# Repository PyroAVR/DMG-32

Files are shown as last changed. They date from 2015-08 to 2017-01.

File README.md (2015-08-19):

Emulator Project
================
I don't have a witty name for this...  This repository contains all the things necessary for making a working Retroarch emulator that fits inside a DMG GameBoy, -or- later, a custom casing with added awesomeness.
Below are the projects which have been used to build this one...

###What changed?
Here's a list of the changes made to the original Adafruit code.
 -Added a new I/O type.  Support for the Pixel interface board.
 -10-retrogame.rules added.  Just copy it into the `/etc/udev/rules.d/` folder!
 -Added retrogame.sh, it's a really handy sysV start script for retrogame!
 -TODO: recompile new retrogame with Pixel interface board support.
Adafruit-Retrogame
==================

Raspberry Pi GPIO-to-USB utility for classic game emulators.

How-to: http://learn.adafruit.com/retro-gaming-with-raspberry-pi

Pre-built version supports the default pin/key mapping shown in the tutorial. For other layouts, edit retrogame.c.

### RetroPie 2.0+ Compatibility

Note that by default retrogame won't work with SDL2 applications that depend on evdev for input events.  Specifically this means applications like the latest version of RetroPie and EmulationStation won't be able to see key events generated by retrogame.  However you can fix this issue by adding a small custom udev rule to make retrogame keyboard events visible to SDL2.

Connect to your Raspberry Pi in a terminal/SSH session and execute the following command to create and edit the file /etc/udev/rules.d/10-retrogame.rules:

```bash
sudo nano /etc/udev/rules.d/10-retrogame.rules
```

Once the nano text editor loads, copy this single line into the file:

```bash
SUBSYSTEM=="input", ATTRS{name}=="retrogame", ENV{ID_INPUT_KEYBOARD}="1"
```

Save the file by pressing Ctrl-O and enter, then press Ctrl-x to exit.  Restart your Raspberry Pi and run retrogame again, now button presses should register in SDL2 applications like the EmulationStation frontend to RetroPie

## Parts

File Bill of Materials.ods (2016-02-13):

Part Name | Count | Description
Resistor, 10KOhm | 14 | 10KOhm 1/4 or 1/8 Watt through-hole
Tactile Swtich | 12 | 6mm square 7.5mm tall 4 pin SPST
LED | 1 | Any color, 3.3 V 3mm
Pin header | 1 | 2x20 Female Pin header, fits on Rpi GPIO header
Atmel ATTiny85 | 1 | ATTiny85 20MHz 8PDIP
Raspberry Pi | 1 | Pi A+ or Zero will fit the enclosure!

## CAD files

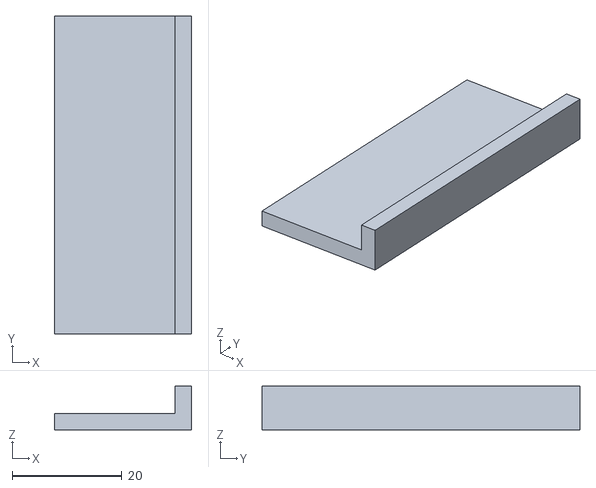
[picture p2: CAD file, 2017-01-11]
case/cardtridge_cover.stl
25.0 x 58.0 x 8.00

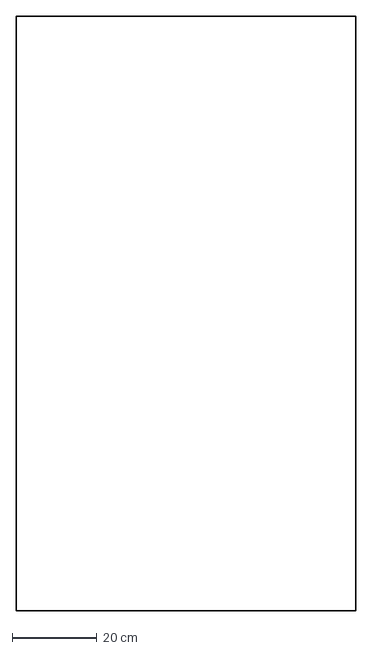
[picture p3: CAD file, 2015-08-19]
Frontboard/BoardOutline.dxf
80.0 x 140.0 cm

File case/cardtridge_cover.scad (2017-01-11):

difference()    {
 cube([25,58,8]);
 translate([0,0,3]) {
  cube([22,58,5]);
 }
}

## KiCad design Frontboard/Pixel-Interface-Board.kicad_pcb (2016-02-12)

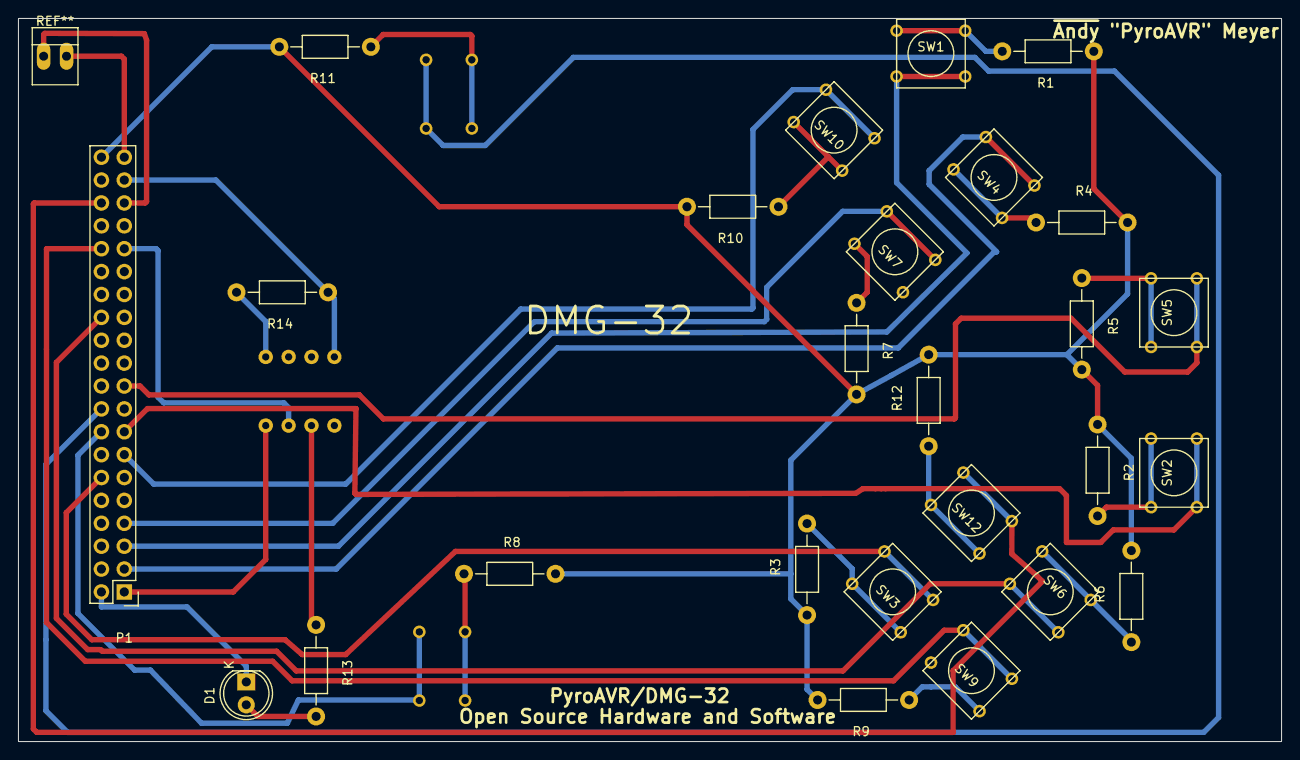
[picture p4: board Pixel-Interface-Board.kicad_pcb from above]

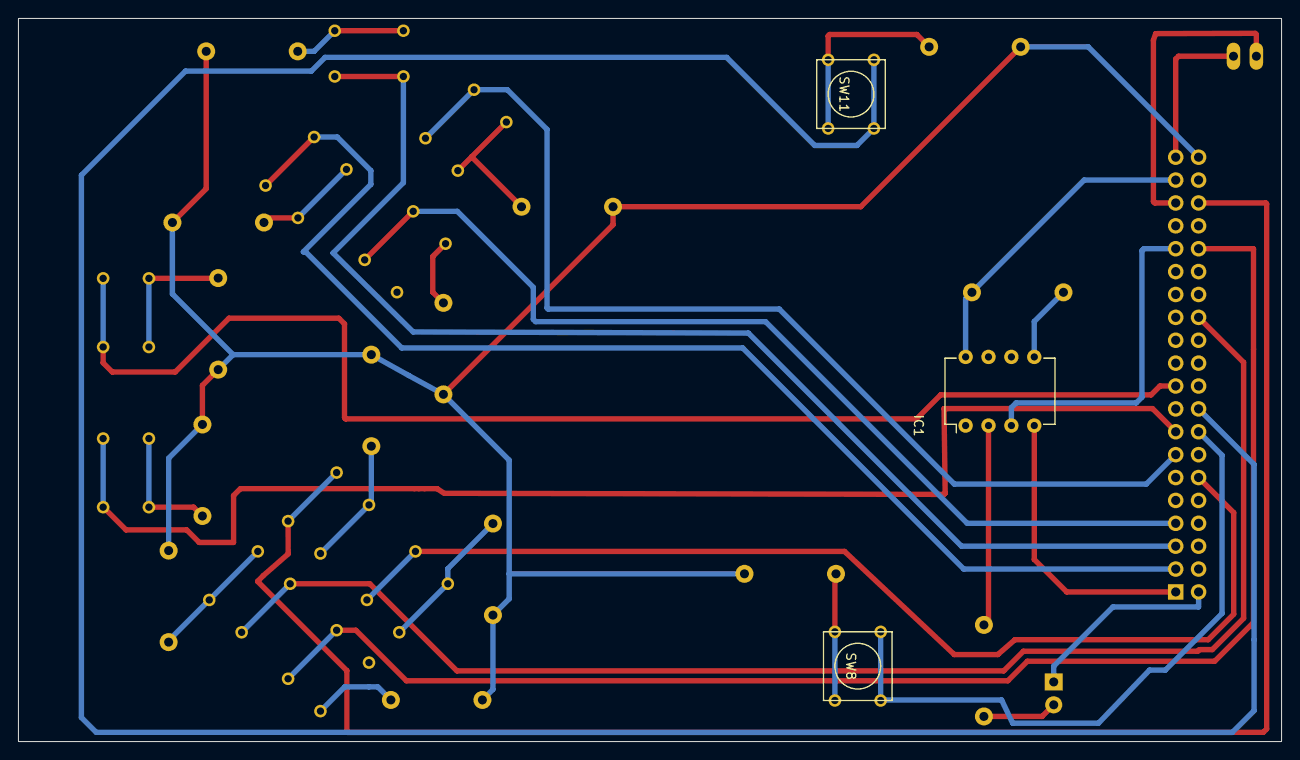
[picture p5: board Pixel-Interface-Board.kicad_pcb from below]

Board: 2 copper layers, 140.2 x 80.3 mm, 29 parts (3 on the bottom side), 31 nets.

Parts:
D1: LED; LED-5MM
IC1: ATTINY85-P; DIP-8_W7.62mm
P1: CONN_02X20; Pin_Header_Straight_2x20
R1, R2, R3, R4, R5, R6, R7, R8, R9, R10, R11, R12, R14: 10K; Resistor_Horizontal_RM10mm
R13: 1K; Resistor_Horizontal_RM10mm
SW1, SW2, SW3, SW4, SW5, SW6, SW7, SW8, SW9, SW10, SW11, SW12: SW_PUSH; SW_PUSH_SMALL

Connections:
/A: P1.5, SW1.2
/B: P1.3, SW4.2
/DOWN: P1.26, SW6.2
/L: P1.16, SW8.2
/LEFT: P1.32, SW9.2
/R: P1.18, SW11.2
/RIGHT: P1.36, SW12.2
/SELECT: P1.15, SW2.2
/START: P1.19, SW5.2
/UART_RX: IC1.3, P1.31
/UP: P1.12, SW3.2
/X: P1.7, SW7.2
/Y: P1.13, SW10.2
GND: D1.1, IC1.4, P1.1, P1.2, P1.9, P1.21, P1.30, P1.34, P1.35
unnamed: D1.2, R13.2
unnamed: IC1.2, R13.1
unnamed: IC1.5, R14.2
unnamed: R1.2, SW1.1
unnamed: R2.2, SW2.1
unnamed: R3.2, SW3.1
unnamed: R4.1, SW4.1
unnamed: R5.1, SW5.1
unnamed: R6.1, SW6.1
unnamed: R7.1, SW7.1
unnamed: R8.1, SW8.1
unnamed: R9.1, SW9.1
unnamed: R10.1, SW10.1
unnamed: R11.1, SW11.1
unnamed: R12.1, SW12.1
VCC: IC1.8, P1.37, P1.39, R14.1
VDD: P1.24, P1.40, R1.1, R2.1, R3.1, R4.2, R5.2, R6.2, R7.2, R8.2, R9.2, R10.2, R11.2, R12.2

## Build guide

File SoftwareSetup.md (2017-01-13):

SOFTWARE SETUP
==========
I/O Pins for Pixel Interface board:
(Make sure these are correct!)
Note that BCM# and GPIO# are synonymous

GPIO NAME         PIN #               FUNCTION          MAP
GPIO3                05               A BUTTON          KEY_A
GPIO2                03               B BUTTON          KEY_B
GPIO4                07               X BUTTON          KEY_X
GPIO27               13               Y BUTTON          KEY_Y
GPIO23               16               L BUTTON          KEY_L
GPIO24               18               R BUTTON          KEY_R
GPIO22               15               SELECT            KEY_N
GPIO10               19               START             KEY_M
GPIO17               11               UP                KEY_UP
GPIO5                26               DOWN              KEY_DOWN
GPIO12               32               LEFT              KEY_LEFT
GPIO16               36               RIGHT             KEY_RIGHT

```C
ioPixel[] = {
//This pin/key table is set up for the tentative Pixel Interface Board,
// which fits quite nicely inside an original DMG Gameboy.
//These mappings are taken directly from the schematic.  For convenience,
//the data has been organized into a neat table, Connectivity Table.ods in this
//repository.
// Input   Output (from /usr/include/linux/input.h)
{   3,     KEY_A  },    // A
{   2,     KEY_B  },    // B
{   4,     KEY_X  },    // X
{  27,     KEY_Y  },    // Y
{  17,     KEY_UP  },   // Up
{   5,     KEY_DOWN  }, // Down
{  12,     KEY_LEFT  }, // Left
{  16,     KEY_RIGHT }, // Right
{  23,     KEY_L  },    // L
{  24,     KEY_R }      // R
{  22,     KEY_N },     // Select
{  10,     KEY_M },     // Start
{  -1,     -1           } }; // END OF LIST, DO NOT CHANGE
```

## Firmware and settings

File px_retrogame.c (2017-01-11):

/*
Pixel RetroGame - An adaptation of Adafruit's Retrogame
http://github.com/Adafruit/Adafruit-retrogame
http://github.com/PyroAVR/DMG-32


Remaps buttons on Raspberry Pi GPIO header
to virtual USB keyboard presses.  Great for classic game emulators!
Retrogame is interrupt-driven and efficient (usually under 0.3% CPU use)
and debounces inputs for glitch-free gaming.

Connect one side of button(s) to GND pin (there are several on the GPIO
header, but see later notes) and the other side to GPIO pin of interest.
Internal pullups are used; no resistors required.  Avoid pins 8 and 10;
these are configured as a serial port by default on most systems (this
can be disabled but takes some doing).  Pin configuration is currently
set in global table; no config file yet.  See later comments.
***
Do not disable the serial port, it is needed for the
power management functionality of the Pixel Interface Board.
Also, a config file is included in the Pixel repository.
***

Must be run as root, i.e. 'sudo ./retrogame &' or configure init scripts
to launch automatically at system startup.
***
The default Pixel image will do this for you.
***

Requires uinput kernel module.  This is typically present on popular
Raspberry Pi Linux distributions but not enabled on some older varieties.
To enable, either type:

    sudo modprobe uinput
  ***
  This is taken care of for you in the Pixel image.
  ***

Or, to make this persistent between reboots, add a line to /etc/modules:

    uinput

Prior versions of this code, when being compiled for use with the Cupcade
or PiGRRL projects, required CUPCADE to be #defined.  This is no longer
the case; instead a test is performed to see if a PiTFT is connected, and
one of two I/O tables is automatically selected.
***
The Pixel code selects its own I/O table by default, and it is
specified in the config file.
***
Written by Phil Burgess for Adafruit Industries, distributed under BSD
License.  Adafruit invests time and resources providing this open source
code, please support Adafruit and open-source hardware by purchasing
products from Adafruit!
***
All the prototypes for the Pixel board, and any necessary components,
were purchased from Adafruit! Thanks for being an inspiration!
***

Copyright (c) 2013 Adafruit Industries, Pixel Productions.
All rights reserved.

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
- Redistributions of source code must retain the above copyright notice,
  this list of conditions and the following disclaimer.
- Redistributions in binary form must reproduce the above copyright notice,
  this list of conditions and the following disclaimer in the documentation
  and/or other materials provided with the distribution.

THIS SOFTWARE IS PROVIDED BY THE COPYRIGHT HOLDERS AND CONTRIBUTORS "AS IS"
AND ANY EXPRESS OR IMPLIED WARRANTIES, INCLUDING, BUT NOT LIMITED TO, THE
IMPLIED WARRANTIES OF MERCHANTABILITY AND FITNESS FOR A PARTICULAR PURPOSE
ARE DISCLAIMED. IN NO EVENT SHALL THE COPYRIGHT HOLDER OR CONTRIBUTORS BE
LIABLE FOR ANY DIRECT, INDIRECT, INCIDENTAL, SPECIAL, EXEMPLARY, OR
CONSEQUENTIAL DAMAGES (INCLUDING, BUT NOT LIMITED TO, PROCUREMENT OF
SUBSTITUTE GOODS OR SERVICES; LOSS OF USE, DATA, OR PROFITS; OR BUSINESS
INTERRUPTION) HOWEVER CAUSED AND ON ANY THEORY OF LIABILITY, WHETHER IN
CONTRACT, STRICT LIABILITY, OR TORT (INCLUDING NEGLIGENCE OR OTHERWISE)
ARISING IN ANY WAY OUT OF THE USE OF THIS SOFTWARE, EVEN IF ADVISED OF THE
POSSIBILITY OF SUCH DAMAGE.
*/
#include "px_retrogame.h"


// A few globals ---------------------------------------------------------

char
  *progName,                         // Program name (for error reporting)
   sysfs_root[] = "/sys/class/gpio", // Location of Sysfs GPIO files
   running      = 1;                 // Signal handler will set to 0 (exit)
volatile unsigned int
  *gpio;                             // GPIO register table
const int
   debounceTime = 20;                // 20 ms for button debouncing


// Some utility functions ------------------------------------------------

// Set one GPIO pin attribute through the Sysfs interface.
int pinConfig(int pin, char *attr, char *value) {
	char filename[50];
	int  fd, w, len = strlen(value);
	sprintf(filename, "%s/gpio%d/%s", sysfs_root, pin, attr);
	if((fd = open(filename, O_WRONLY)) < 0) return -1;
	w = write(fd, value, len);
	close(fd);
	return (w != len); // 0 = success
}

// Un-export any Sysfs pins used; don't leave filesystem cruft.  Also
// restores any GND pins to inputs.  Write errors are ignored as pins
// may be in a partially-initialized state.
void cleanup() {
	char buf[50];
	int  fd, i;
	sprintf(buf, "%s/unexport", sysfs_root);
	if((fd = open(buf, O_WRONLY)) >= 0) {
		for(i=0; io[i].pin >= 0; i++) {
			// Restore GND items to inputs
			if(io[i].key == GND)
				pinConfig(io[i].pin, "direction", "in");
			// And un-export all items regardless
			sprintf(buf, "%d", io[i].pin);
			write(fd, buf, strlen(buf));
		}
		close(fd);
	}
}

// Quick-n-dirty error reporter; print message, clean up and exit.
void err(char *msg) {
	printf("%s: %s.  Try 'sudo %s'.\n", progName, msg, progName);
	cleanup();
	exit(1);
}

// Interrupt handler -- set global flag to abort main loop.
void signalHandler(int n) {
	running = 0;
}

// Detect Pi board type.  Doesn't return super-granular details,
// just the most basic distinction needed for GPIO compatibility:
// 0: Pi 1 Model B revision 1
// 1: Pi 1 Model B revision 2, Model A, Model B+, Model A+
// 2: Pi 2 Model B

static int boardType(void) {
	FILE *fp;
	char  buf[1024], *ptr;
	int   n, board = 1; // Assume Pi1 Rev2 by default

	// Relies on info in /proc/cmdline.  If this becomes unreliable
	// in the future, alt code below uses /proc/cpuinfo if any better.
#if 1
	if((fp = fopen("/proc/cmdline", "r"))) {
		while(fgets(buf, sizeof(buf), fp)) {
			if((ptr = strstr(buf, "mem_size=")) &&
			   (sscanf(&ptr[9], "%x", &n) == 1) &&
			   (n == 0x3F000000)) {
				board = 2; // Appears to be a Pi 2
				break;
			} else if((ptr = strstr(buf, "boardrev=")) &&
			          (sscanf(&ptr[9], "%x", &n) == 1) &&
			          ((n == 0x02) || (n == 0x03))) {
				board = 0; // Appears to be an early Pi
				break;
			}
		}
		fclose(fp);
	}
#else
	char s[8];
	if((fp = fopen("/proc/cpuinfo", "r"))) {
		while(fgets(buf, sizeof(buf), fp)) {
			if((ptr = strstr(buf, "Hardware")) &&
			   (sscanf(&ptr[8], " : %7s", s) == 1) &&
			   (!strcmp(s, "BCM2709"))) {
				board = 2; // Appears to be a Pi 2
				break;
			} else if((ptr = strstr(buf, "Revision")) &&
			          (sscanf(&ptr[8], " : %x", &n) == 1) &&
			          ((n == 0x02) || (n == 0x03))) {
				board = 0; // Appears to be an early Pi
				break;
			}
		}
		fclose(fp);
	}
#endif

	return board;
}

// Main stuff ------------------------------------------------------------

#define PI1_BCM2708_PERI_BASE 0x20000000
#define PI1_GPIO_BASE         (PI1_BCM2708_PERI_BASE + 0x200000)
#define PI2_BCM2708_PERI_BASE 0x3F000000
#define PI2_GPIO_BASE         (PI2_BCM2708_PERI_BASE + 0x200000)
#define BLOCK_SIZE            (4*1024)
#define GPPUD                 (0x94 / 4)
#define GPPUDCLK0             (0x98 / 4)

int main(int argc, char *argv[]) {

	// A few arrays here are declared with 32 elements, even though
	// values aren't needed for io[] members where the 'key' value is
	// GND.  This simplifies the code a bit -- no need for mallocs and
	// tests to create these arrays -- but may waste a handful of
	// bytes for any declared GNDs.
	char                   buf[50],      // For sundry filenames
	                       c,            // Pin input value ('0'/'1')
	                       board;        // 0=Pi1Rev1, 1=Pi1Rev2, 2=Pi2
	int                    fd,           // For mmap, sysfs, uinput
	                       i, j,         // Asst. counter
	                       bitmask,      // Pullup enable bitmask
	                       timeout = -1, // poll() timeout
	                       intstate[32], // Last-read state
	                       extstate[32], // Debounced state
	                       lastKey = -1; // Last key down (for repeat)
	unsigned long          bitMask, bit; // For Vulcan pinch detect
	volatile unsigned char shortWait;    // Delay counter
	struct input_event     keyEv, synEv; // uinput events
	struct pollfd          p[32];        // GPIO file descriptors

	progName = argv[0];             // For error reporting
	signal(SIGINT , signalHandler); // Trap basic signals (exit cleanly)
	signal(SIGKILL, signalHandler);

	// Modified for Pixel devices, so io is set to use ioPixel.
	//As the DMG-32 board doesn't have an EEPROM, no detection is possible.
  //It does have an ATTiny85 though, so it may later be able to emulate this?
  //The only obstacle is that the ATTiny85 is on the Pi's UART pins, and the SPI
  //pins are occupied as GPIO.
  io = ioPixel;

//The interface board does not support older Pis, which likely do not have
//enough GPIO

//The DMG-32 board has pullup resistors on it, whoops!  This probably isn't needed.

	// ----------------------------------------------------------------
	// Although Sysfs provides solid GPIO interrupt handling, there's
	// no interface to the internal pull-up resistors (this is by
	// design, being a hardware-dependent feature).  It's necessary to
	// grapple with the GPIO configuration registers directly to enable
	// the pull-ups.  Based on GPIO example code by Dom and Gert van
	// Loo on elinux.org

	if((fd = open("/dev/mem", O_RDWR | O_SYNC)) < 0)
		err("Can't open /dev/mem");
	gpio = mmap(            // Memory-mapped I/O
	  NULL,                 // Any adddress will do
	  BLOCK_SIZE,           // Mapped block length
	  PROT_READ|PROT_WRITE, // Enable read+write
	  MAP_SHARED,           // Shared with other processes
	  fd,                   // File to map
	  (board == 2) ?
	   PI2_GPIO_BASE :      // -> GPIO registers
	   PI1_GPIO_BASE);

	close(fd);              // Not needed after mmap()
	if(gpio == MAP_FAILED) err("Can't mmap()");
	// Make combined bitmap of pullup-enabled pins:
	for(bitmask=i=0; io[i].pin >= 0; i++)
		if(io[i].key != GND) bitmask |= (1 << io[i].pin);
	gpio[GPPUD]     = 2;                    // Enable pullup
	for(shortWait=150;--shortWait;);        // Min 150 cycle wait
	gpio[GPPUDCLK0] = bitmask;              // Set pullup mask
	for(shortWait=150;--shortWait;);        // Wait again
	gpio[GPPUD]     = 0;                    // Reset pullup registers
	gpio[GPPUDCLK0] = 0;
	(void)munmap((void *)gpio, BLOCK_SIZE); // Done with GPIO mmap()


//From here on out, we're just enabling pins.
	// ----------------------------------------------------------------
	// All other GPIO config is handled through the sysfs interface.

	sprintf(buf, "%s/export", sysfs_root);
	if((fd = open(buf, O_WRONLY)) < 0) // Open Sysfs export file
		err("Can't open GPIO export file");
	for(i=j=0; io[i].pin >= 0; i++) { // For each pin of interest...
		sprintf(buf, "%d", io[i].pin);
		write(fd, buf, strlen(buf));             // Export pin
		pinConfig(io[i].pin, "active_low", "0"); // Don't invert
		if(io[i].key == GND) {
			// Set pin to output, value 0 (ground)
			if(pinConfig(io[i].pin, "direction", "out") ||
			   pinConfig(io[i].pin, "value"    , "0"))
				err("Pin config failed (GND)");
		} else {
			// Set pin to input, detect rise+fall events
			if(pinConfig(io[i].pin, "direction", "in") ||
			   pinConfig(io[i].pin, "edge"     , "both"))
				err("Pin config failed");
			// Get initial pin value
			sprintf(buf, "%s/gpio%d/value",
			  sysfs_root, io[i].pin);
			// The p[] file descriptor array isn't necessarily
			// aligned with the io[] array.  GND keys in the
			// latter are skipped, but p[] requires contiguous
			// entries for poll().  So the pins to monitor are
			// at the head of p[], and there may be unused
			// elements at the end for each GND.  Same applies
			// to the intstate[] and extstate[] arrays.
			if((p[j].fd = open(buf, O_RDONLY)) < 0)
				err("Can't access pin value");
			intstate[j] = 0;
			if((read(p[j].fd, &c, 1) == 1) && (c == '0'))
				intstate[j] = 1;
			extstate[j] = intstate[j];
			p[j].events  = POLLPRI; // Set up poll() events
			p[j].revents = 0;
			j++;
		}
	} // 'j' is now count of non-GND items in io[] table
	close(fd); // Done exporting


	// ----------------------------------------------------------------
	// Set up uinput
//In need of changes, most likely, as DMG-32 does not support SDL2
#if 1
	// Retrogame normally uses /dev/uinput for generating key events.
	// Cupcade requires this and it's the default.  SDL2 (used by
	// some newer emulators) doesn't like it, wants /dev/input/event0
	// instead.  Enable that code by changing to "#if 0" above.
	if((fd = open("/dev/uinput", O_WRONLY | O_NONBLOCK)) < 0)
		err("Can't open /dev/uinput");
	if(ioctl(fd, UI_SET_EVBIT, EV_KEY) < 0)
		err("Can't SET_EVBIT");
	for(i=0; io[i].pin >= 0; i++) {
		if(io[i].key != GND) {
			if(ioctl(fd, UI_SET_KEYBIT, io[i].key) < 0)
				err("Can't SET_KEYBIT");
		}
	}
	if(ioctl(fd, UI_SET_KEYBIT, vulcanKey) < 0) err("Can't SET_KEYBIT");
	struct uinput_user_dev uidev;
	memset(&uidev, 0, sizeof(uidev));
	snprintf(uidev.name, UINPUT_MAX_NAME_SIZE, "retrogame");
	uidev.id.bustype = BUS_USB;
	uidev.id.vendor  = 0x1;
	uidev.id.product = 0x1;
	uidev.id.version = 1;
	if(write(fd, &uidev, sizeof(uidev)) < 0)
		err("write failed");
	if(ioctl(fd, UI_DEV_CREATE) < 0)
		err("DEV_CREATE failed");
#else // SDL2 prefers this event methodology
	if((fd = open("/dev/input/event0", O_WRONLY | O_NONBLOCK)) < 0)
		err("Can't open /dev/input/event0");
#endif

	// Initialize input event structures
	memset(&keyEv, 0, sizeof(keyEv));
	keyEv.type  = EV_KEY;
	memset(&synEv, 0, sizeof(synEv));
	synEv.type  = EV_SYN;
	synEv.code  = SYN_REPORT;
	synEv.value = 0;

	// 'fd' is now open file descriptor for issuing uinput events


	// ----------------------------------------------------------------
	// Monitor GPIO file descriptors for button events.  The poll()
	// function watches for GPIO IRQs in this case; it is NOT
	// continually polling the pins!  Processor load is near zero.

	while(running) { // Signal handler can set this to 0 to exit
		// Wait for IRQ on pin (or timeout for button debounce)
		if(poll(p, j, timeout) > 0) { // If IRQ...
			for(i=0; i<j; i++) {       // Scan non-GND pins...
				if(p[i].revents) { // Event received?
					// Read current pin state, store
					// in internal state flag, but
					// don't issue to uinput yet --
					// must wait for debounce!
					lseek(p[i].fd, 0, SEEK_SET);
					read(p[i].fd, &c, 1);
					if(c == '0')      intstate[i] = 1;
					else if(c == '1') intstate[i] = 0;
					p[i].revents = 0; // Clear flag
				}
			}
			timeout = debounceTime; // Set timeout for debounce
			c       = 0;            // Don't issue SYN event
			// Else timeout occurred
		} else if(timeout == debounceTime) { // Button debounce timeout
			// 'j' (number of non-GNDs) is re-counted as
			// it's easier than maintaining an additional
			// remapping table or a duplicate key[] list.
			bitMask = 0L; // Mask of buttons currently pressed
			bit     = 1L;
			for(c=i=j=0; io[i].pin >= 0; i++, bit<<=1) {
				if(io[i].key != GND) {
					// Compare internal state against
					// previously-issued value.  Send
					// keystrokes only for changed states.
					if(intstate[j] != extstate[j]) {
						extstate[j] = intstate[j];
						keyEv.code  = io[i].key;
						keyEv.value = intstate[j];
						write(fd, &keyEv,
						  sizeof(keyEv));
						c = 1; // Follow w/SYN event
						if(intstate[j]) { // Press?
							// Note pressed key
							// and set initial
							// repeat interval.
							lastKey = i;
							timeout = repTime1;
						} else { // Release?
							// Stop repeat and
							// return to normal
							// IRQ monitoring
							// (no timeout).
							lastKey = timeout = -1;
						}
					}
					j++;
					if(intstate[i]) bitMask |= bit;
				}
			}

			// If the "Vulcan nerve pinch" buttons are pressed,
			// set long timeout -- if this time elapses without
			// a button state change, esc keypress will be sent.
			if((bitMask & vulcanMask) == vulcanMask)
				timeout = vulcanTime;
		} else if(timeout == vulcanTime) { // Vulcan timeout occurred
			// Send keycode (MAME exits or displays exit menu)
			keyEv.code = vulcanKey;
			for(i=1; i>= 0; i--) { // Press, release
				keyEv.value = i;
				write(fd, &keyEv, sizeof(keyEv));
				usleep(10000); // Be slow, else MAME flakes
				write(fd, &synEv, sizeof(synEv));
				usleep(10000);
			}
			timeout = -1; // Return to normal processing
			c       = 0;  // No add'l SYN required
		} else if(lastKey >= 0) { // Else key repeat timeout
			if(timeout == repTime1) timeout = repTime2;
			else if(timeout > 30)   timeout -= 5; // Accelerate
			c           = 1; // Follow w/SYN event
			keyEv.code  = io[lastKey].key;
			keyEv.value = 2; // Key repeat event
			write(fd, &keyEv, sizeof(keyEv));
		}
		if(c) write(fd, &synEv, sizeof(synEv));
	}

	// ----------------------------------------------------------------
	// Clean up

	ioctl(fd, UI_DEV_DESTROY); // Destroy and
	close(fd);                 // close uinput
	cleanup();                 // Un-export pins

	puts("Done.");

	return 0;
}

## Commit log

2015-07-27 Added initial PCB stuff. Probably doesn't work.
    [Emulatorv1pcb.sch, _saved_Emulatorv1pcb.sch]
2015-08-19 Almost done with the Front Board!
    [BoardOutline.dxf, Pixel-Interface-Board.dsn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]
2015-09-23 Probably update the board and stuff...
    [Pixel-Interface-Board-B_Cu.gbr, Pixel-Interface-Board-B_SilkS.gbr, Pixel-Interface-Board-Dwgs_User.gbr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]
2015-11-12 Fixed the interface board, FINALLY.
    [Pixel-Interface-Board.dsn, Pixel-Interface-Board.kicad_pcb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]
2016-01-24 Fixed R trace to fit within OSHPark specs. Unfortunately, a very long trace circling the entire board has resulted from this.
    [Pixel-Interface-Board.kicad_pcb]
2016-01-24 Added board outline to the proper layer.
    [Pixel-Interface-Board.kicad_pcb]
2016-01-24 Oooh, silkscreen...
    [Pixel-Interface-Board.kicad_pcb]
2016-01-27 Directories moved, .gitignore added. Major changes to Frontboard design. Header was completely backwards, fixed now, pins re-arranged. Table coming shortly.
    [BoardOutline.dxf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]
2016-01-27 Added table to show hardware->software connections.
    [Connectivity Table.ods]
2016-01-27 Tentative fixes for ioPixel, as well as removing potential confusion due to board auto-detection, which is thankfully not necessary.
    [px_retrogame.c]
2016-01-30 removing vulcanMask
    removed vulcanMask assignment so escape is never sent. Very likely to be causing crashes in testing where not all pins are connected.
    [px_retrogame.c]
2016-01-31 Fixed Gcode, hopefully. Z-depth for isolation lowered, Z-depth for drill increased.
    [Pixel-Interface-Board-B.Cu.gbl, Pixel-Interface-Board-B.Mask.gbs, Pixel-Interface-Board-B.SilkS.gbo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]
2016-01-31 Switched vulcanKey to Q to remove confusion. Will configure retroarch to use Q to raise menu overlays and include retroarch.cfg
2016-01-31 Retroarch config for DMG-32. Hopefully final.
    [retroarch.cfg]
2016-02-06 Minor edits to circuitboard front which may help eliminate issues with CAM processing.
    [Pixel-Interface-Board.kicad_pcb]
2016-02-06 Fixed Gerber, re-exported. Alignment and spacing looking good. Gcode added into repo again, generated by FlatCAM.
    [Pixel-Interface-Board-B.Cu.gbl, Pixel-Interface-Board-B.Mask.gbs, Pixel-Interface-Board-B.SilkS.gbo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]
2016-02-06 Shifted Gcode up by 96 mm to center lower-left corner near (0,0). Shift applied by PyroAVR/Gcode-Manipulator
2016-02-12 Added power port to pcb, rpi micro usb power port no longer used. Exported new Gerber and Gcode.
    [Pixel-Interface-Board-B.Cu.gbl, Pixel-Interface-Board-B.Mask.gbs, Pixel-Interface-Board-B.SilkS.gbo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]
2016-02-13 Started working on BOM
    [Bill of Materials.ods]
2017-01-11 changes made for use w/ Kitsch-Bent PCB.
    [cardtridge_cover.scad, cardtridge_cover.stl]
2017-01-11 Re-enabled pull-up resistor setter for safety.
2017-01-13 Moved pin due to pullup on BCM7 bot working. 7->5
